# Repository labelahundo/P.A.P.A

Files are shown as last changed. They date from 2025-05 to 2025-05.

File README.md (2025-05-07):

# P.A.P.A
Proyecto escolar

Baliza climática en prototipo para monitoreo ambiental.

## Estado del proyecto

Prototipo en desarrollo.

## Tecnologías utilizadas

- Python
- MicroPython
- PHP
- HTML
- MySQL

## Documentación

La instalación y el uso están detallados en la documentación del proyecto.

## Contribución

Colaboración abierta entre estudiantes.

## Autores

Juan Esteban Campos Navarrete
Alfredo Lopez Sernas
Peña Savala Carlos Mateo
Rigel Flores Zamudio

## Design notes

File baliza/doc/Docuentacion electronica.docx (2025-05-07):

## Lista de Componentes:

2 × Paneles solares – 6 V, 230 mA

1 × Sensor ADXL345 (Acelerómetro)

1 × Sensor BME680 (Presión, temperatura, humedad y calidad de aire)

1 × Módulo LoRa RYLR998 (868/915 MHz)

1 × Raspberry Pi Pico (versión original, sin WiFi)

2 × Módulos J5019

1 × Boost Converter DC-DC (0.9 V – 5 V a 5 V, x10)

1 × Controlador de carga solar MPPT SD05CRMA (1 A)

4 × Baterías recargables 18650 de ion de litio, 2400 mAh

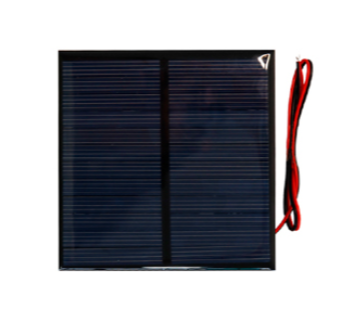
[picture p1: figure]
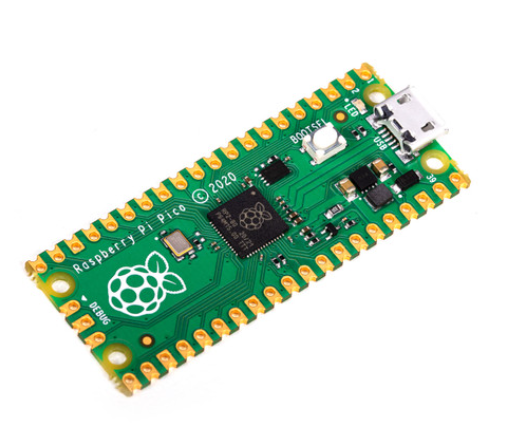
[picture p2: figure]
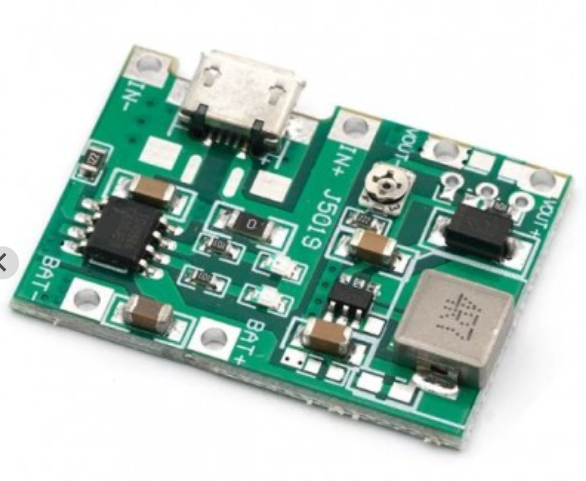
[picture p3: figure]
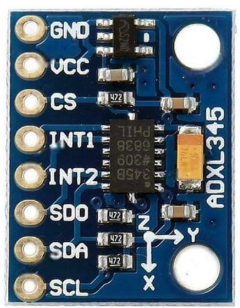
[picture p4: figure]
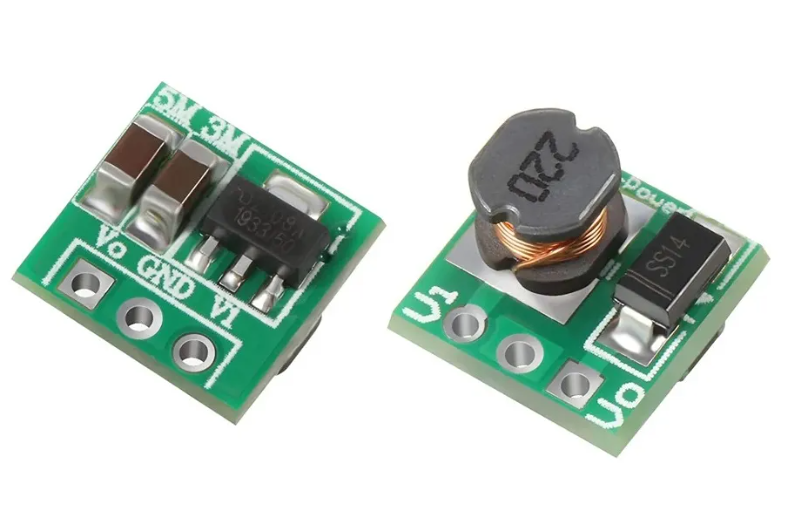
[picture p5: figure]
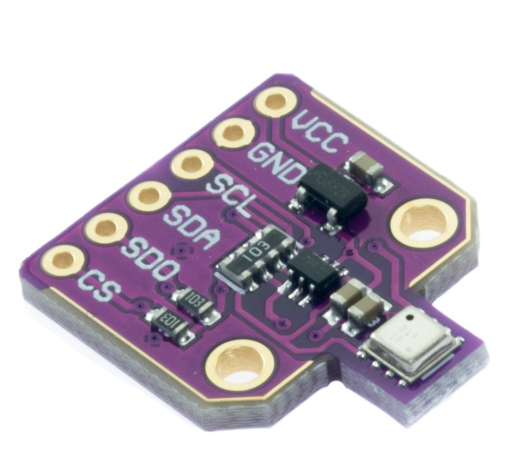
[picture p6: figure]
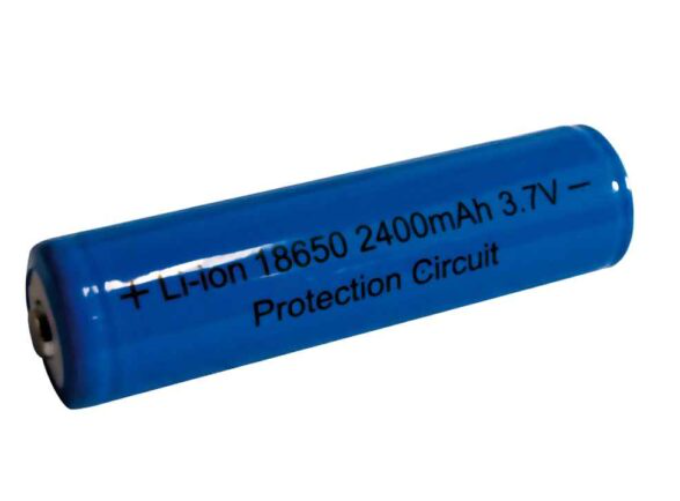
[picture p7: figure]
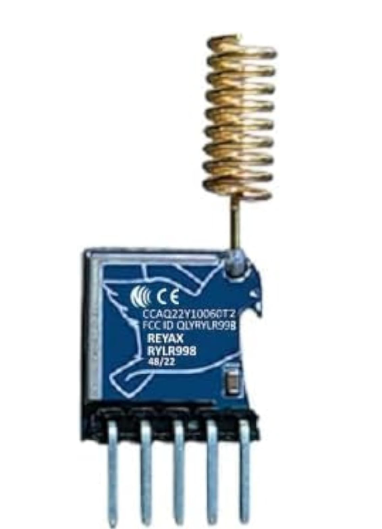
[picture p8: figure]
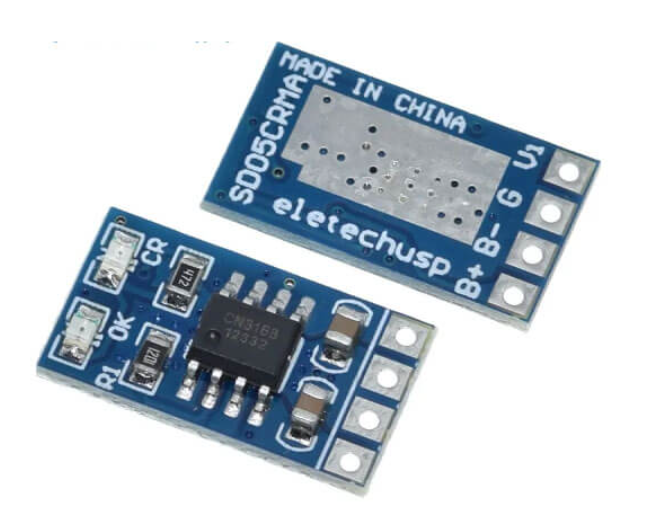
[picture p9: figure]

configuración de los modulos lora para comunicación a distancia:

RYLR998

868/915MHz LoRa® Antenna Transceiver Module

◆ NUVOTON MCU & Semtech LoRa® Engine

◆ Excellent blocking immunity

◆ Smart receiving power saving mode

◆ High sensitivity

◆ Control easily by AT commands

◆ Built-in antenna

◆ Command support data encryption

◆ Certification: FCC, NCC, CE

Modulo A:

AT+RESET

AT+MODE=0

AT+IPR=115200

AT+ADDRESS=101

AT+NETWORKID=12

AT+BAND=915000000,M

AT+PARAMETER=9,7,1,12

AT+CRFOP=22

Modulo B:

AT+RESET

AT+MODE=0

AT+IPR=115200

AT+ADDRESS=102

AT+NETWORKID=12

AT+BAND=915000000,M

AT+PARAMETER=9,7,1,12

AT+CRFOP=22

Linsta de comandos validos para el modulo usado en este proyecto:

https://reyax.com//upload/products_download/download_file/LoRa_AT_Command_RYLR998_RYLR498_EN.pdf

Para conocer la configuracion basica del modulo se usan estos comandos:

AT+ADDRESS? # Dirección del módulo

AT+NETWORKID? # ID de red

AT+BAND? # Frecuencia

AT+PARAMETER? # Parámetros LoRa (SF, BW, CR, preámbulo)

AT+CRFOP? # Potencia de salida

AT+IPR? # Baud rate del UART

AT+CPIN? # Contraseña (si se ha establecido)

AT+MODE? # Modo de operación (activo, sleep, ahorro)

AT+UID? # ID único del módulo

AT+VER? # Versión de firmware

#### Specification

Item | Min. | Typical | Max. | Unit | Condition
VDD Power Supply | 2.3 | 3.3 | 3.6 | V | VDD
RF Output Power Range | 0 | | 22 | dBm
Filter insertion loss | 1 | 2 | 3 | dB
RF Sensitivity | -129 | | | dBm
RF Input Level | | | 10 | dBm
Frequency Range | 820 | 868/915 | 960 | MHz
Frequency Accuracy | | ±10 | | ppm
Transmit Mode Current | | 140 | | mA | RFOP = +22 dBm
Receive Mode Current | | 17.5 | | mA
Sleep mode Current | | 10 | | uA | AT+MODE=1 @VDD=+3.3V
Smart receiving power saving mode average current | 0.06 | 2.65 | 5.5 | mA | 2.65mA @AT+MODE=2,1000,1000 If you need lower current consumption, you can adjust the AT+MODE=2 time duty.
Baud rate | 300 | 115200 | 115200 | bps | 8, N, 1
Digital Input Level High | 0.7*VDD | | VDD | V | VIH
Digital Input Level Low | 0 | | 0.3*VDD | V | VIL
Digital Output Level High | 0.9 | | VDD | V | VOH
Digital Output Level Low | | | 0.1 | V | VOL
Cycling (erase / write) Flash data memory | | 200 | | K | Cycles
Weight | | 1.83 | | g
Operating Temperature | -40 | 25 | +85 | ˚C

Alimentacion de los modulos:

Módulo | Consumo típico | Consumo pico máximo | Notas
ADXL345 | ~0.1 µA en standby | ~ 40 µA in modo medición | El consumo energetico puede depender de la intensidad y recurrencia con la que es solicitado al modulo.
BME680 | ~0.15 mA modo bajo consumo | ~12 mA modo full | Un poco más alto pero muy manejable.
LoRa RYLR998 | ~15 μA en standby y 17.5 mA en recepcion. | ~140 mA cuando transmite | Aquí es donde hay un pico más alto.

El 3V3 (OUT) de la Raspberry Pi Pico pentrega 300 mA de corriente estable.

Total máximo de consumo: ~152.04 mA.

Añadiendo el consumo en operacion de la raspberri pi pico usada en este proyecto (alrededor de 20-25 mA ), el total de consumo aproximado seria de 177.04 mA

ESPECIFICACIONES TÉCNICAS - Módulo BME680:

◦ Voltaje de alimentación: 3.3 V a 5 V DC

◦ Interfaz de comunicación: I2C o SPI (3.3 V)

◦ Rango de presión: 300 - 1100 hPa

◦ Precisión de presión: ±0.12 hPa (aprox. ±1 m)

• Rango de temperatura: -40 °C a 85 °C

• Resolución de temperatura: 0.01 °C

• Precisión de temperatura: ±1 °C

• Rango de humedad relativa: 0 - 100 % RH

• Precisión de humedad relativa: ±3 %

• Frecuencia máxima de muestreo: 157 Hz

• VCC: Voltaje de alimentación (3.3-5 V DC)

• GND: Tierra

• SCL: Línea de reloj para I2C / SPI

• SDA: Línea de datos para I2C / MOSI para SPI

• SDO: MISO para SPI (no usado en I2C)

• CS: Selección de chip para SPI (no usado en I2C)

ESPECIFICACIONES TÉCNICAS - Sensor ADXL345:

• Voltaje de operación: 3V - 5V

• Consumo de corriente: 23 µA en medición y 0.1 µA en standby

• Alta sensibilidad

• Rango Acelerómetro: +/- 2g, 4g, 8g y 16g

• Resolución de hasta 13 bits a ± 16 g (manteniendo 4 mg / LSB)

• Grados de libertad: 3 ejes

• Regulador de voltaje integrado

• VCC: Alimentación, normalmente (3.3-5 V DC)

• GND: Tierra

• SDA: Línea de datos para comunicación I2C

• SCL: Línea de reloj para comunicación I2C

• CS: Pin de selección de chip para comunicación SPI

• SDO: Pin para seleccionar la dirección I2C o para SPI

ESPECIFICACIONES TÉCNICAS - Módulo RYLR998:

• Rango de frecuencia: 902 - 928 MHz (Mexico y Estados Unidos)

• Potencia de transmisión: Hasta 22 dBm (ajustable)

• Sensibilidad de recepción: -129 dBm

• Interfaz de comunicación: UART

• Protocolo de comunicación: Comandos AT

• Consumo de corriente en modo reposo: 15 μA

• Consumo de corriente en modo transmisión: Hasta 140 mA

• Consumo de corriente en modo recepción: Hasta 17.5 mA

• Temperatura de funcionamiento: -40 °C a +85 °C

• Antena: Integrada, con conector para antena externa I-PEX® MHF4®

• Controlador: MCU NUVOTON

• VDD: Alimentación del módulo 3.3v.

• NRST: Pin de reinicio (activo bajo).

• RXD: Entrada de datos UART

• TXD: Salida de datos UART

• GND: Tierra

# === CONEXIONES FÍSICAS ===

# Raspberry Pi Pico → Sensor ADXL345 (Acelerómetro)

# GP4 (pin 6) → SDA

# GP5 (pin 7) → SCL

# 3V3 (pin 36) → VCC

# GND (pin 38) → GND

# CS → 3V3 (activar modo I2C)

# SDO → GND (direccion I2C 0x53)

# Raspberry Pi Pico → Sensor BME680

# GP4 (pin 6) → SDA (comparten bus con ADXL345)

# GP5 (pin 7) → SCL

# 3V3 (pin 36) → VCC

# GND (pin 38) → GND

# CS → 3V3 (activar modo I2C)

# SDO → 3V3 (direccion I2C 0x77, diferente al ADXL345)

# Raspberry Pi Pico → Módulo LoRa RYLR998

# GP0 (pin 1) → RXD (del LoRa)

# GP1 (pin 2) → TXD (del LoRa)

# 3V3 (pin 36) → VCC

# GND (pin 38) → GND

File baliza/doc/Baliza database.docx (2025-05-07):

Información general:

- Nombre de la base de datos: baliza
- Versión MYSQL: 8.0.39
- Propósito: Documentar el monitoreo ambiental general de diferentes módulos de medición.
- Autor: Juan Esteban Campos Navarrete
- Fecha de creación: Aproximadamente una semana antes del presente informe.
- Estado actual: Contiene 3 tablas:
  - modulos
  - registro_general
  - msg.

Diagrama Entidad-Relación:

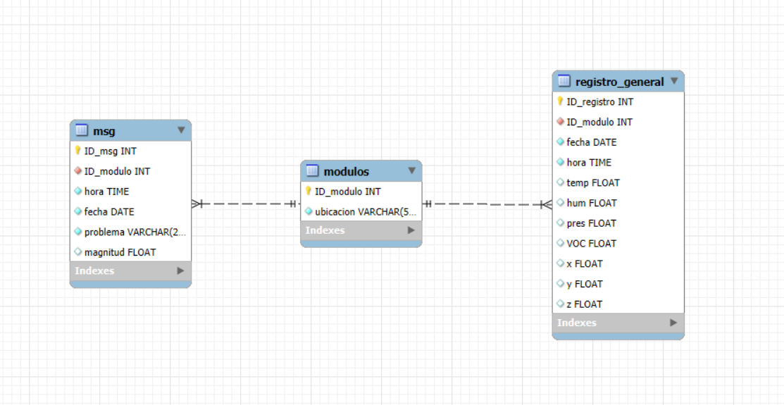
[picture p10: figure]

Tablas y estructuras:

🔹 Tabla: modulos

Columna | Tipo de dato | Nulo | Clave | Descripción
ID_modulo | INT (AUTO_INCREMENT) | NO | PRIMARY KEY | Identificador único del módulo
ubicacion | VARCHAR(50) | NO | | Las coordenadas geográficas del módulo

Propósito: Almacena los diferentes módulos de monitoreo instalados en ubicaciones específicas.

🔹 Tabla: registro_general

Columna | Tipo de dato | Nulo | Clave | Descripción
ID_registro | INT (AUTO_INCREMENT) | NO | PRIMARY KEY | Identificador único del registro
ID_modulo | INT | NO | FOREIGN KEY | Relación con modulos(ID_modulo)
fecha | DATE | NO | | Fecha del registro
hora | TIME | NO | | Hora del registro
temp | FLOAT | Sí | | Temperatura medida
hum x, y, z FLOAT Sí Movimiento en los 3 ejes | FLOAT | Sí | | Humedad medida
pres | FLOAT | Sí | | Presión atmosférica
VOC | FLOAT | Sí | | Compuestos orgánicos volátiles
x | FLOAT | Sí | | Movimiento en el eje x
y | FLOAT | Sí | | Movimiento en el eje y
z | FLOAT | Sí | | Movimiento en el eje z

Propósito: Guarda las lecturas ambientales generales por módulo.

🔹 Tabla: msg

Columna | Tipo de dato | Nulo | Clave | Descripción
ID_msg | INT (AUTO_INCREMENT) | NO | PRIMARY KEY | Identificador de la alerta
ID_modulo | INT | NO | FOREIGN KEY | Relación con modulos(ID_modulo)
fecha | DATE | NO | | Fecha del mensaje
hora | TIME | NO | | Hora del mensaje
problema | VARCHAR(20) | NO | | Causa del problema registrado
magnitud | FLOAT | Sí | | Valor asociado al problema

Propósito: Registra mensajes de error o advertencias.

Relaciones entre tablas:

registro_general.ID_modulo → modulos.ID_modulo (muchos registros por módulo)

msg.ID_modulo → modulos.ID_modulo (muchos mensajes por módulo)

Un solo módulo puede tener muchos mensajes de error y registros de datos, pero cada mensaje y registro pertenece a un solo módulo.

Usuarios y permisos:

Usuario | Permisos otorgados | Propósito
bal_ins | SELECT | Usuario solo para lectura(Muestra los datos en página web)
bal_read | INSERT | Usuario para insertar datos(Inserta los datos de las balizas)

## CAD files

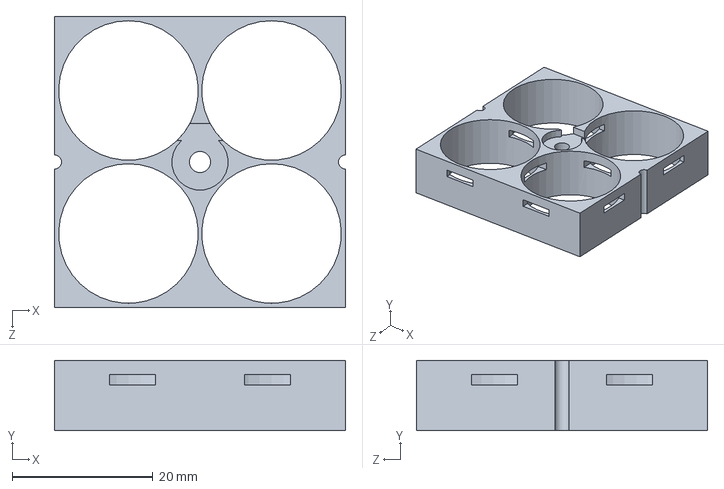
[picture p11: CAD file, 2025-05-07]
baliza/modelo/p1_baterias.SLDPRT
41.3 x 10.0 x 41.3 mm

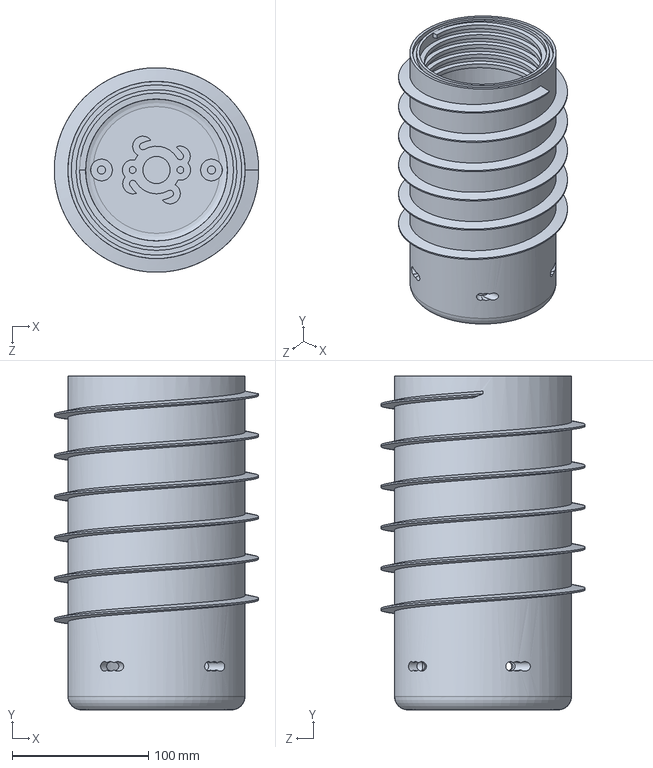
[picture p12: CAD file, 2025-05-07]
baliza/modelo/carcasa baliza.SLDPRT
150.0 x 245.0 x 150.0 mm

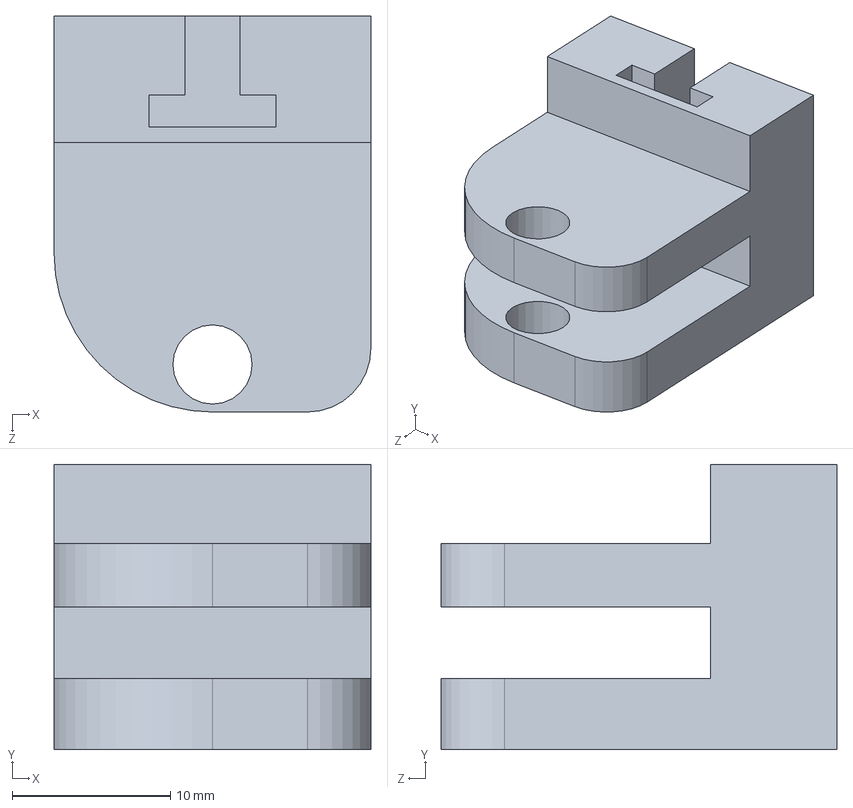
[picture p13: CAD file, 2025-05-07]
baliza/modelo/chaveta-sosten.SLDPRT
20.0 x 18.0 x 25.0 mm

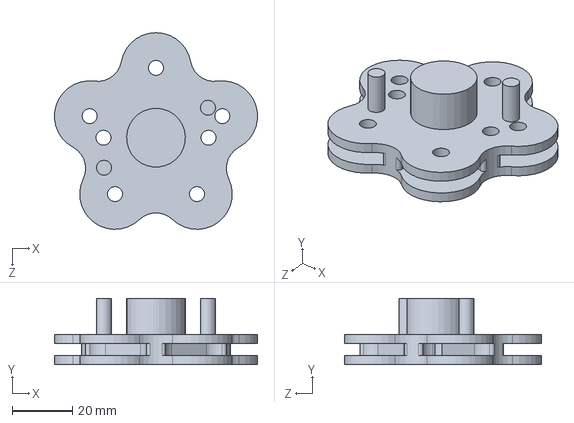
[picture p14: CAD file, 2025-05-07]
baliza/modelo/Part4.SLDPRT
67.6 x 22.0 x 65.6 mm

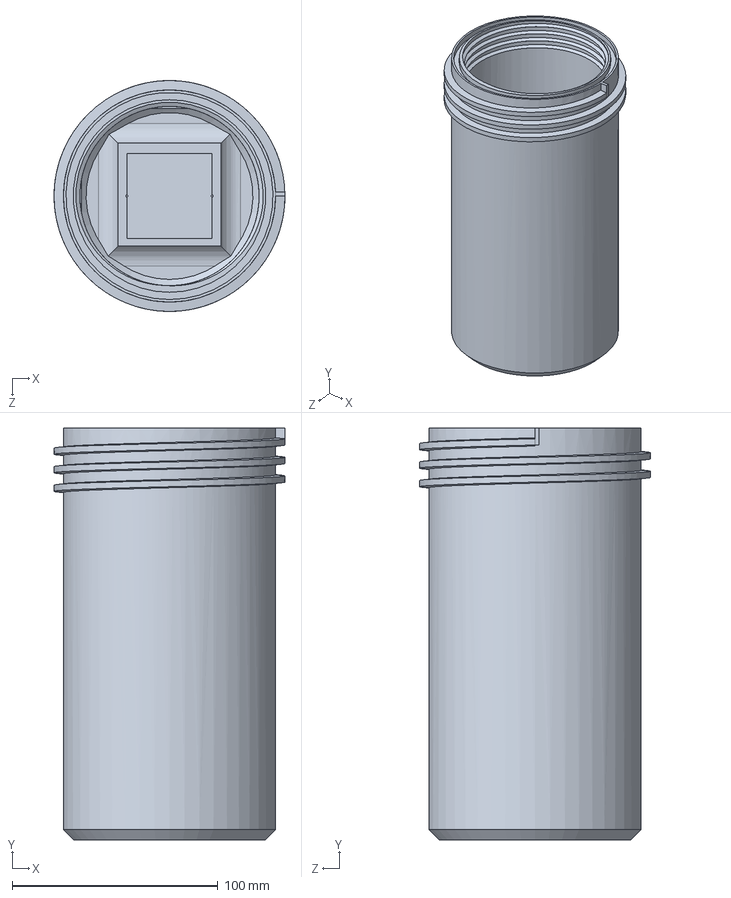
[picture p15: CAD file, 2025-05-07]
baliza/modelo/fondo.SLDPRT
112.1 x 200.0 x 112.1 mm

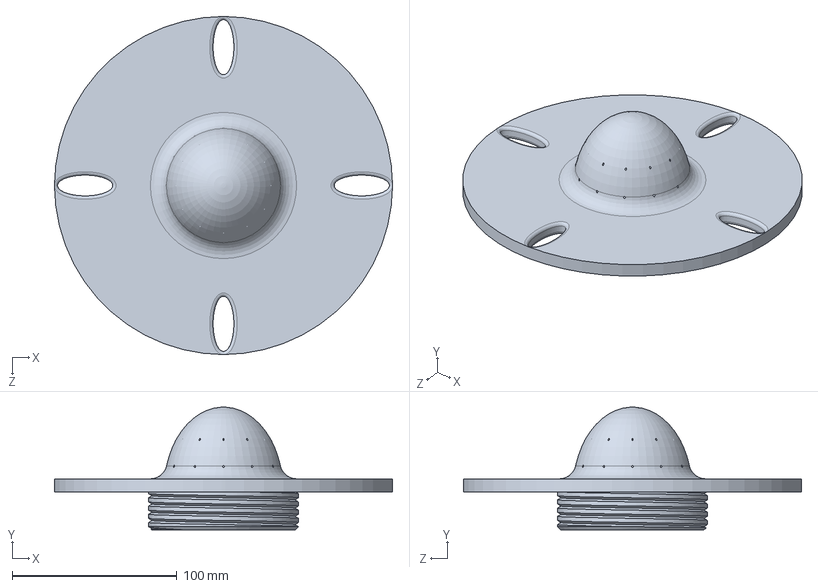
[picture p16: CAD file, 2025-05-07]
baliza/modelo/tapa.SLDPRT
205.0 x 74.5 x 205.0 mm

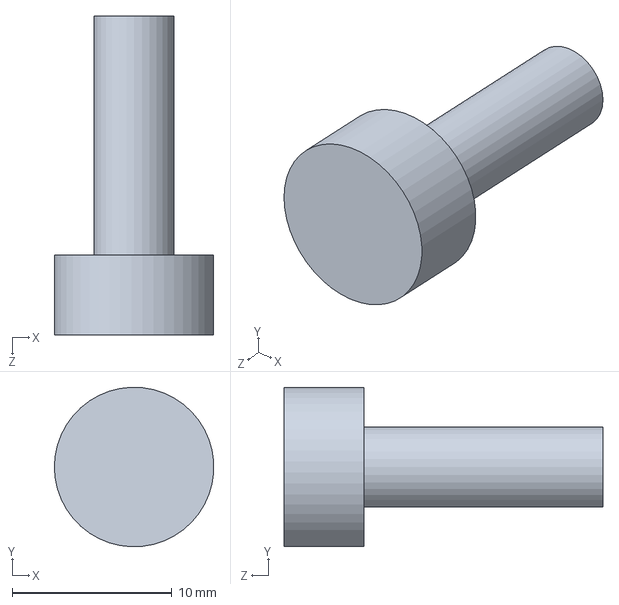
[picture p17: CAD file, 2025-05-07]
baliza/modelo/chaveta.SLDPRT
9.99 x 9.99 x 20.0 mm

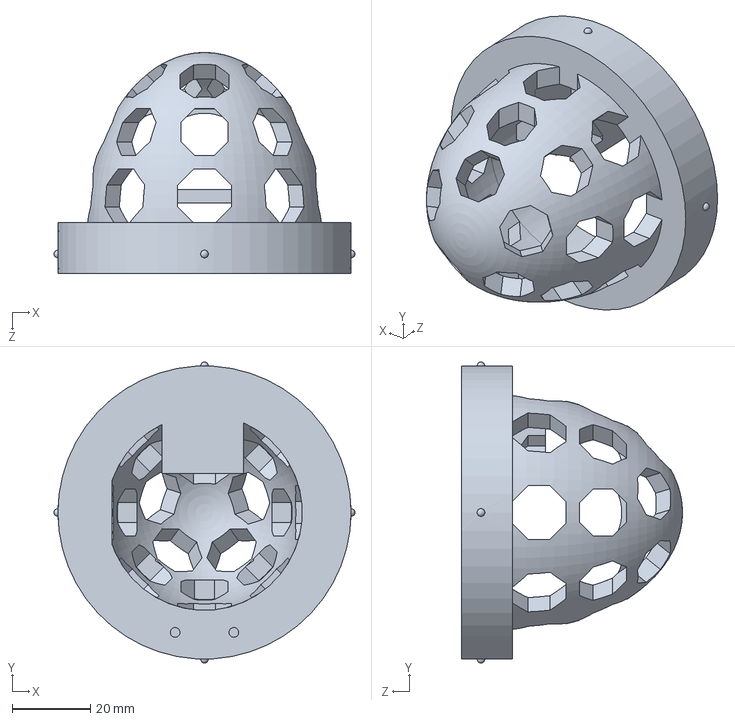
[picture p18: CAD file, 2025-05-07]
baliza/modelo/gorro.SLDPRT
76.9 x 76.9 x 56.5 mm

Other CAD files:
baliza/modelo/stl/Part4.STL
baliza/modelo/stl/carcasa baliza.STL
baliza/modelo/stl/chaveta-sosten.STL
baliza/modelo/stl/chaveta.STL
baliza/modelo/stl/fondo.STL
baliza/modelo/stl/gorro.STL
baliza/modelo/stl/p1_baterias.STL
baliza/modelo/stl/tapa.STL

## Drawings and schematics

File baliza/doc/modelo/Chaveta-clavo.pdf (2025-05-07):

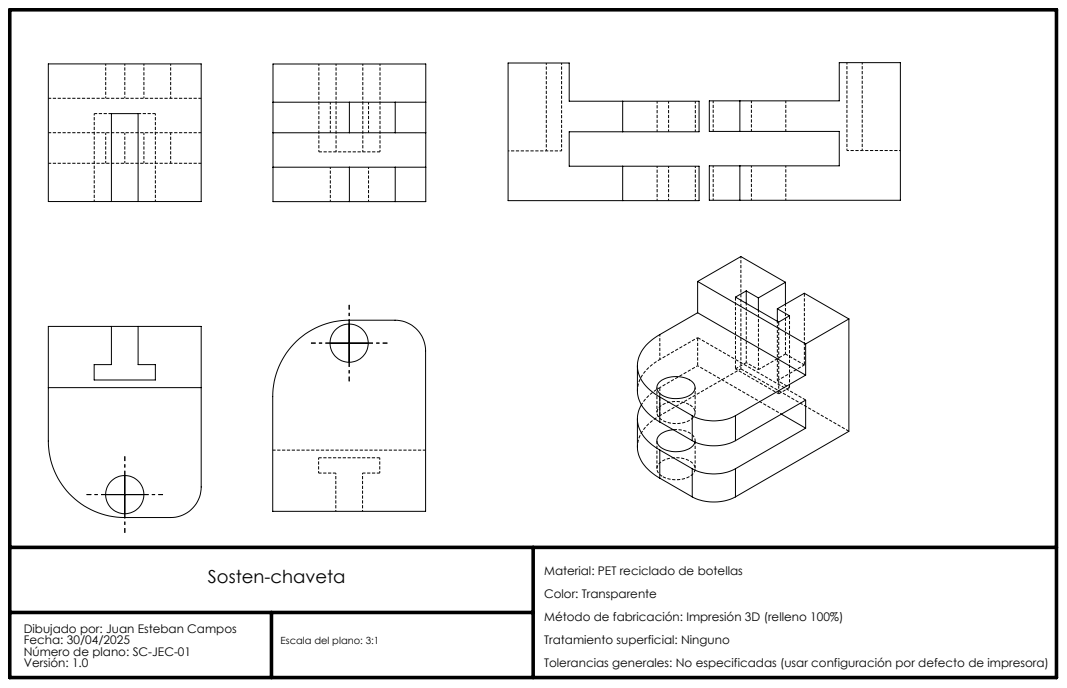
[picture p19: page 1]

Sosten-chaveta | Material: PET reciclado de botellas Color: Transparente Método de fabricación: Impresión 3D (relleno 100%) Tratamiento superficial: Ninguno Tolerancias generales: No especificadas (usar configuración por defecto de impresora)

Dibujado por: Juan Esteban Campos Fecha: 30/04/2025 Número de plano: SC-JEC-01 Versión: 1.0 | Escala del plano: 3:1

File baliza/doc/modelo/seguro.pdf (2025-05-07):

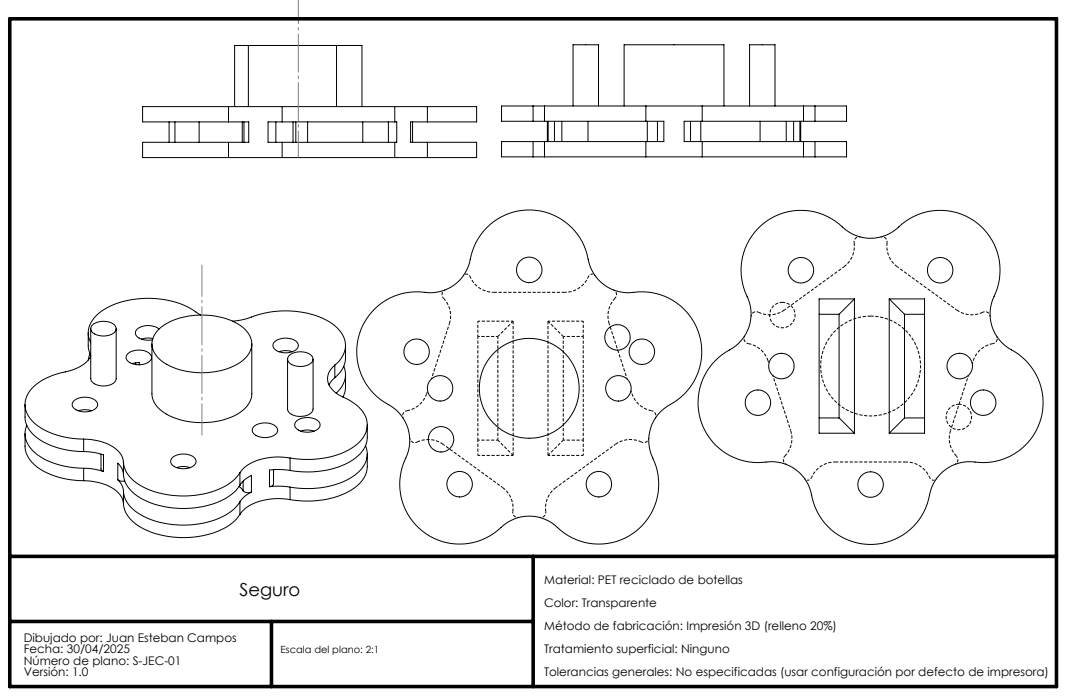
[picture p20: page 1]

Seguro | Material: PET reciclado de botellas Color: Transparente Método de fabricación: Impresión 3D (relleno 20%) Tratamiento superficial: Ninguno Tolerancias generales: No especificadas (usar configuración por defecto de impresora)

Dibujado por: Juan Esteban Campos Fecha: 30/04/2025 Número de plano: S-JEC-01 Versión: 1.0 | Escala del plano: 2:1

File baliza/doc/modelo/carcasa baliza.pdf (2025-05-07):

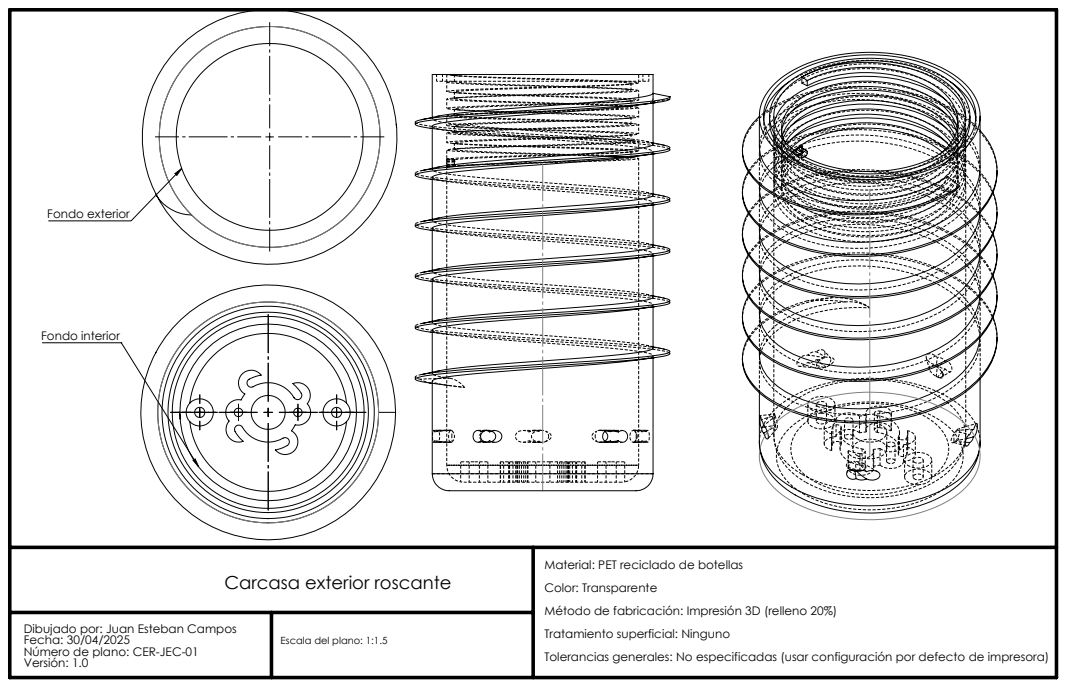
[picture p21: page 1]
Fondo exterior; Fondo interior

Carcasa exterior roscante | Material: PET reciclado de botellas Color: Transparente Método de fabricación: Impresión 3D (relleno 20%) Tratamiento superficial: Ninguno Tolerancias generales: No especificadas (usar configuración por defecto de impresora)

Dibujado por: Juan Esteban Campos Fecha: 30/04/2025 Número de plano: CER-JEC-01 Versión: 1.0 | Escala del plano: 1:1.5

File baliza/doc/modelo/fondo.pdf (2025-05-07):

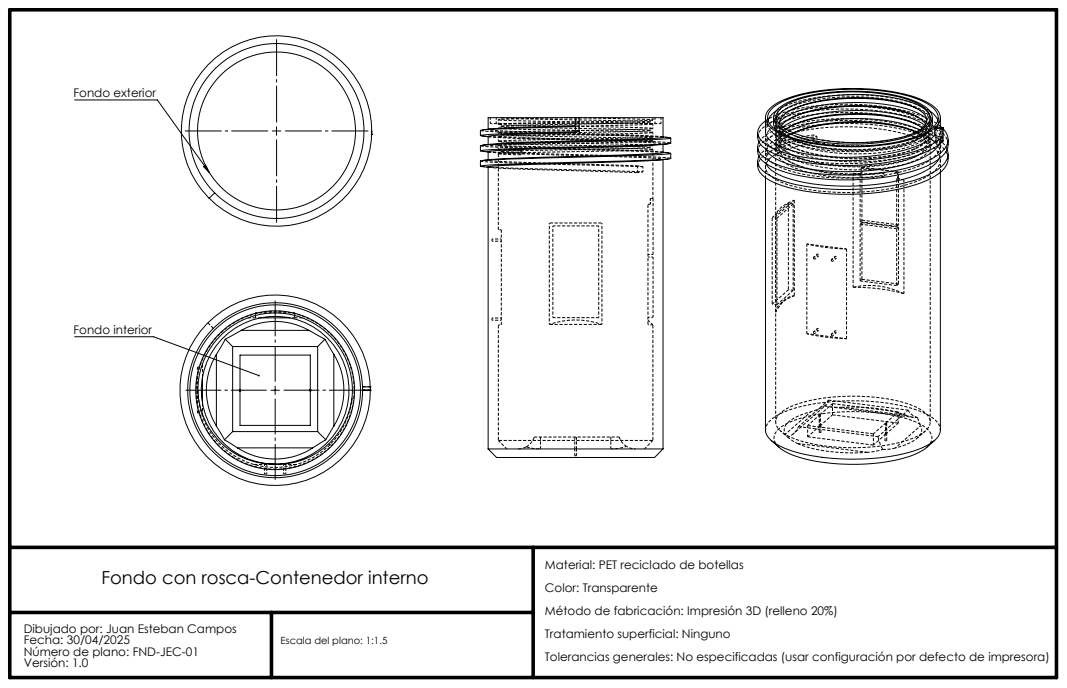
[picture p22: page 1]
Fondo exterior; Fondo interior

Fondo con rosca-Contenedor interno | Material: PET reciclado de botellas Color: Transparente Método de fabricación: Impresión 3D (relleno 20%) Tratamiento superficial: Ninguno Tolerancias generales: No especificadas (usar configuración por defecto de impresora)

Dibujado por: Juan Esteban Campos Fecha: 30/04/2025 Número de plano: FND-JEC-01 Versión: 1.0 | Escala del plano: 1:1.5

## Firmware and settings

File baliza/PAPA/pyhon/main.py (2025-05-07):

import pymysql
import random
import time
import serial
import asyncio
from datetime import datetime
import re

# Configuración
PUERTO = 'COM9'
BAUDIOS = 115200
MI_DIRECCION = '102'

class ReceptorDatos:
    def __init__(self):
        # Conexion a la base de datos
        self.conn = pymysql.connect(
            host='localhost',
            user='val_ins',
            password='123',
            database='baliza'
        )
        self.cursor = self.conn.cursor()
        
        # Conexion al puerto serie
        self.uart = serial.Serial(PUERTO, BAUDIOS, timeout=2)
        print(f"Conexin serial establecida en {PUERTO} a {BAUDIOS} baudios")

    def insertar_modulo(self, id_modulo):
        """Insertar un nuevo módulo con ubicación aleatoria"""
        try:
            ubicacion = f"Ubicacion_{random.randint(1, 100)}"
            query = "INSERT INTO modulos (ID_modulo, ubicacion) VALUES (%s, %s)"
            self.cursor.execute(query, (id_modulo, ubicacion))
            self.conn.commit()
            print(f"Módulo {id_modulo} registrado en ubicación {ubicacion}")
            return True
        except pymysql.IntegrityError:
            print(f"Módulo {id_modulo} ya existe en la base de datos")
            return True
        except Exception as e:
            print(f"Error al insertar módulo {id_modulo}: {e}")
            return False

    def enviar_confirmacion(self, direccion, tipo_mensaje):
        """Enviar  de confirmación al módulo"""
        try:
            fecha_hora = datetime.now().strftime("%Y-%m-%d %H:%M:%S")
            mensaje = f"{fecha_hora}||{tipo_mensaje}"
            comando = f"AT+SEND={direccion},{len(mensaje)},{mensaje}\r\n"
            self.uart.write(comando.encode('utf-8'))
            print(f"ACK enviado a {direccion} para mensaje tipo {tipo_mensaje}")
            return True
        except Exception as e:
            print(f"Error al enviar ACK: {e}")
            return False

    def guardar_datos_generales(self, direccion, fecha, hora, datos):
        """Guardar datos tipo 1 en registro_general"""
        try:
            query = """
            INSERT INTO registro_general 
            (ID_modulo, fecha, hora, temp, hum, pres, VOC, x, y, z) 
            VALUES (%s, %s, %s, %s, %s, %s, %s, %s, %s, %s)
            """
            valores = (
                direccion, fecha, hora,
                datos.get('temp'), datos.get('hum'), datos.get('pres'), datos.get('voc'),
                datos.get('x'), datos.get('y'), datos.get('z')
            )
            self.cursor.execute(query, valores)
            self.conn.commit()
            print(f"Datos generales guardados para módulo {direccion}")
            return True
        except Exception as e:
            print(f"Error al guardar datos generales: {e}")
            return False

    def guardar_alerta(self, direccion, fecha, hora, tipo, datos):
        """Guardar alertas tipo 2 y 3 en msg"""
        try:
            if tipo == '2':
                problema = "alta_temp"
                magnitud = datos.get('temp')
            else:  # tipo 3
                problema = "movimiento"
                magnitud = datos.get('magnitud')
            
            query = """
            INSERT INTO msg 
            (ID_modulo, fecha, hora, problema, magnitud) 
            VALUES (%s, %s, %s, %s, %s)
            """
            self.cursor.execute(query, (direccion, fecha, hora, problema, magnitud))
            self.conn.commit()
            print(f"Alerta tipo {tipo} guardada para módulo {direccion}")
            return True
        except Exception as e:
            print(f"Error al guardar alerta: {e}")
            return False

    async def procesar_mensaje_tipo1(self, direccion, fecha, hora, datos):
        """Procesar mensajes tipo 1 (datos generales)"""
        try:
            # Extraer datos del formato: T:val C H:val% P:valhPa G:valkh X:val Y:val Z:val
            datos_dict = {}
            partes = datos.split()
            
            for parte in partes:
                if ':' in parte:
                    clave, valor = parte.split(':', 1)
                    clave = clave.lower()
                    # Eliminar unidades y convertir a float
                    valor = float(re.sub(r'[^0-9.-]', '', valor))
                    datos_dict[clave] = valor
            
            if not {'t', 'h', 'p', 'g', 'x', 'y', 'z'}.issubset(datos_dict.keys()):
                print("Faltan datos en el mensaje tipo 1")
                return False
            
            return self.guardar_datos_generales(
                direccion, fecha, hora,
                {'temp': datos_dict['t'], 'hum': datos_dict['h'], 'pres': datos_dict['p'],
                 'voc': datos_dict['g'], 'x': datos_dict['x'], 'y': datos_dict['y'], 'z': datos_dict['z']}
            )
        except Exception as e:
            print(f"Error al procesar mensaje tipo 1: {e}")
            return False

    async def procesar_mensaje_tipo2(self, direccion, fecha, hora, datos):
        """Procesar mensajes tipo 2 (alerta temperatura)"""
        try:
            temp = float(re.sub(r'[^0-9.-]', '', datos.split()[0]))
            return self.guardar_alerta(
                direccion, fecha, hora, '2',
                {'temp': temp}
            )
        except Exception as e:
            print(f"Error al procesar mensaje tipo 2: {e}")
            return False

    async def procesar_mensaje_tipo3(self, direccion, fecha, hora, datos):
        """Procesar mensajes tipo 3 (alerta movimiento)"""
        try:
            # Extraer valores X, Y, Z del formato: X:val Y:val Z:val
            valores = re.findall(r"[-+]?\d*\.\d+|\d+", datos)
            if len(valores) >= 3:
                magnitud = (sum(float(v)**2 for v in valores[:3]))**0.5
            else:
                magnitud = None
            
            return self.guardar_alerta(
                direccion, fecha, hora, '3',
                {'magnitud': magnitud}
            )
        except Exception as e:
            print(f"Error al procesar mensaje tipo 3: {e}")
            return False

    async def procesar_mensaje_tipo4(self, direccion, fecha, hora):
        """Procesar mensajes tipo 4 (registro/emparejamiento)"""
        try:
            # Verificar si el módulo ya esta registrado
            self.cursor.execute("SELECT 1 FROM modulos WHERE ID_modulo = %s", (direccion,))
            if not self.cursor.fetchone():
                if not self.insertar_modulo(direccion):
                    return False
            
            # Enviar confirmación
            return self.enviar_confirmacion(direccion, '4')
        except Exception as e:
            print(f"Error al procesar mensaje tipo 4: {e}")
            return False

    async def manejar_mensaje(self, mensaje):
        """Manejar mensajes entrantes y dirigirlos al procesador adecuado"""
        if not mensaje.startswith("+RCV="):
            return False
            
        try:
            # Parsear el mensaje LoRa
            payload = mensaje[5:].strip()
            partes = payload.split(',', 2)
            
            if len(partes) < 3:
                print("Formato de mensaje invalido (partes insuficientes)")
                return False
                
            direccion = partes[0].strip()
            longitud = partes[1].strip()
            contenido = partes[2].strip()
            
            # Validar dirección y longitud
            if not direccion.isdigit() or not longitud.isdigit():
                print("Dirección o longitud invlidas")
                return False
                
            # Parsear contenido: fecha_hora|tipo|datos
            match = re.search(r"([\d\-]+\s[\d:]+)\s*\|(\d)\|(.*)", contenido)
            if not match:
                print("Formato de contenido invalido")
                return False
                
            fecha_hora, tipo, datos = match.groups()
            fecha, hora = fecha_hora.split()
            
            # Procesar según el tipo de mensaje
            if tipo == '1':
                exito = await self.procesar_mensaje_tipo1(direccion, fecha, hora, datos)
            elif tipo == '2':
                exito = await self.procesar_mensaje_tipo2(direccion, fecha, hora, datos)
            elif tipo == '3':
                exito = await self.procesar_mensaje_tipo3(direccion, fecha, hora, datos)
            elif tipo == '4':
                exito = await self.procesar_mensaje_tipo4(direccion, fecha, hora)
            else:
                print(f"Tipo de mensaje desconocido: {tipo}")
                return False
            
            # Enviar confirmación para tipos 1, 2 y 3
            if exito and tipo in ('1', '2', '3'):
                return self.enviar_confirmacion(direccion, tipo)
            
            return exito
                
        except Exception as e:
            print(f"Error al manejar mensaje: {e}")
            return False

    async def escuchar_mensajes(self):
        """Bucle principal para escuchar mensajes"""
        print("Iniciando servidor. Esperando mensajes...")
        while True:
            await asyncio.sleep(0.1)
            if self.uart.in_waiting:
                try:
                    raw = self.uart.readline()
                    
                    # Solo continuar si la línea tiene algo y parece comenzar como mensaje válido
                    if b'+RCV=' in raw:
                        try:
                            mensaje = raw.decode('utf-8').strip()
                            if mensaje.startswith("+RCV="):
                                print(f"Mensaje recibido: {mensaje}")
                                await self.manejar_mensaje(mensaje)
                            else:
                                print(f"Mensaje no relevante: {mensaje}")
                        except UnicodeDecodeError:
                            print(f"Error de decodificación: bytes no válidos -> {raw}")
                    else:
                        try:
                            # Intentar decodificar cualquier otra cosa para depuración
                            otro = raw.decode('utf-8', errors='ignore').strip()
                            if otro:
                                print(f"Mensaje no procesado: {otro}")
                        except Exception:
                            print(f"Bytes ignorados: {raw}")
                            
                except Exception as e:
                    print(f"Error al procesar mensaje: {e}")


    async def cerrar(self):
        """Cerrar conexiones adecuadamente"""
        self.uart.close()
        self.cursor.close()
        self.conn.close()
        print("Conexiones cerradas correctamente")

async def main():
    receptor = ReceptorDatos()
    try:
        await receptor.escuchar_mensajes()
    except KeyboardInterrupt:
        print("\nDeteniendo servidor...")
    except Exception as e:
        print(f"Error crítico: {e}")
    finally:
        await receptor.cerrar()

if __name__ == '__main__':
    asyncio.run(main())

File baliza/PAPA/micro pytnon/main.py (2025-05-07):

import uasyncio as asyncio
from machine import I2C, UART, Pin
from bme680 import BME680_I2C
from ADXL345 import ADXL345

# === Inicialización de hardware ===
i2c = I2C(0, scl=Pin(5), sda=Pin(4), freq=100_000)
uart = UART(0, baudrate=115200)
i2c_lock = asyncio.Lock()


# === Inicialización de sensores ===
bme = BME680_I2C(i2c=i2c, address=0x77)
adxl = ADXL345(i2c, 0x53)

# === Variables globales para promedios ===
lecturas = {
    "temp": [], "hum": [], "pres": [], "gas": [],
    "x": [], "y": [], "z": []
}

# Últimos valores para detectar cambios bruscos
ult_x = ult_y = ult_z = 0

async def leer_adxl345():
    global ult_x, ult_y, ult_z
    while True:
        async with i2c_lock:
            x = adxl.xValue
            y = adxl.yValue
            z = adxl.zValue

        dx, dy, dz = abs(x - ult_x), abs(y - ult_y), abs(z - ult_z)
        if dx > 8 or dy > 8 or dz > 8:
            alerta = f"movimiento brusco X:{dx} Y:{dy} Z:{dz}"
            uart.write(f"AT+SEND=102,{len(alerta)},{alerta}\r\n")
            print("[ALERTA] Movimiento brusco:", alerta.strip())

        ult_x, ult_y, ult_z = x, y, z

        # Acumular para promedio
        lecturas["x"].append(x)
        lecturas["y"].append(y)
        lecturas["z"].append(z)

        await asyncio.sleep(1)

async def leer_bme680():
    while True:
        async with i2c_lock:
            temp = bme.temperature
            hum = bme.humidity
            pres = bme.pressure
            gas = bme.gas / 1000 if bme.gas else 0

        print("BME680 → Temp: {:.1f} °C | Hum: {:.1f}% | Pres: {:.1f} hPa | Gas: {:.1f} kh".format(
            temp, hum, pres, gas))

        # Alerta por temperatura crítica
        if temp > 70:
            alerta = f"¡ALERTA! Temperatura muy alta: {temp:.1f} °C\r\n"
            uart.write(f"AT+SEND=102,{len(alerta)},{alerta}")
            print("[ALERTA] Temperatura:", alerta.strip())

        # Acumular para promedio
        lecturas["temp"].append(temp)
        lecturas["hum"].append(hum)
        lecturas["pres"].append(pres)
        lecturas["gas"].append(gas)

        await asyncio.sleep(120)

async def enviar_lora():
    while True:
        await asyncio.sleep(600)  # Esperar 10 minutos

        # Calcular promedios
        promedio = lambda lista: sum(lista) / len(lista) if lista else 0

        temp = promedio(lecturas["temp"])
        hum = promedio(lecturas["hum"])
        pres = promedio(lecturas["pres"])
        gas = promedio(lecturas["gas"])
        x = promedio(lecturas["x"])
        y = promedio(lecturas["y"])
        z = promedio(lecturas["z"])

        paquete = "AVG → T:{:.1f}C H:{:.1f}% P:{:.1f}hPa G:{:.1f}kh X:{:.1f} Y:{:.1f} Z:{:.1f}".format(
            temp, hum, pres, gas, x, y, z)
        mensaje = f"AT+SEND=102,{len(paquete)},{paquete}\r\n"

        uart.write(mensaje)
        print("[LORA] Enviado promedio:", mensaje.strip())

        # Limpiar listas después del envío
        for key in lecturas:
            lecturas[key].clear()

async def recibir_lora():
    while True:
        if uart.any():
            mensaje = uart.readline()
            if mensaje:
                print("LoRa Respuesta:", mensaje.decode().strip())
        await asyncio.sleep(0.1)

# === Función principal ===
async def main():
    asyncio.create_task(leer_adxl345())
    asyncio.create_task(leer_bme680())
    asyncio.create_task(enviar_lora())
    asyncio.create_task(recibir_lora())
    while True:
        await asyncio.sleep(60)

# === Iniciar ejecución ===
asyncio.run(main())
